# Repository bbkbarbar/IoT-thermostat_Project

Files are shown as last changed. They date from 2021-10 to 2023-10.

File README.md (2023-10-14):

# IoT Thermostat v4.0.2

Custom made thermostat for building's heating control with capability of timing heat-phases when energy price is discounted.
It also has capability of different custom-interfaces (e.g.: show values on smart-mirror, etc.)

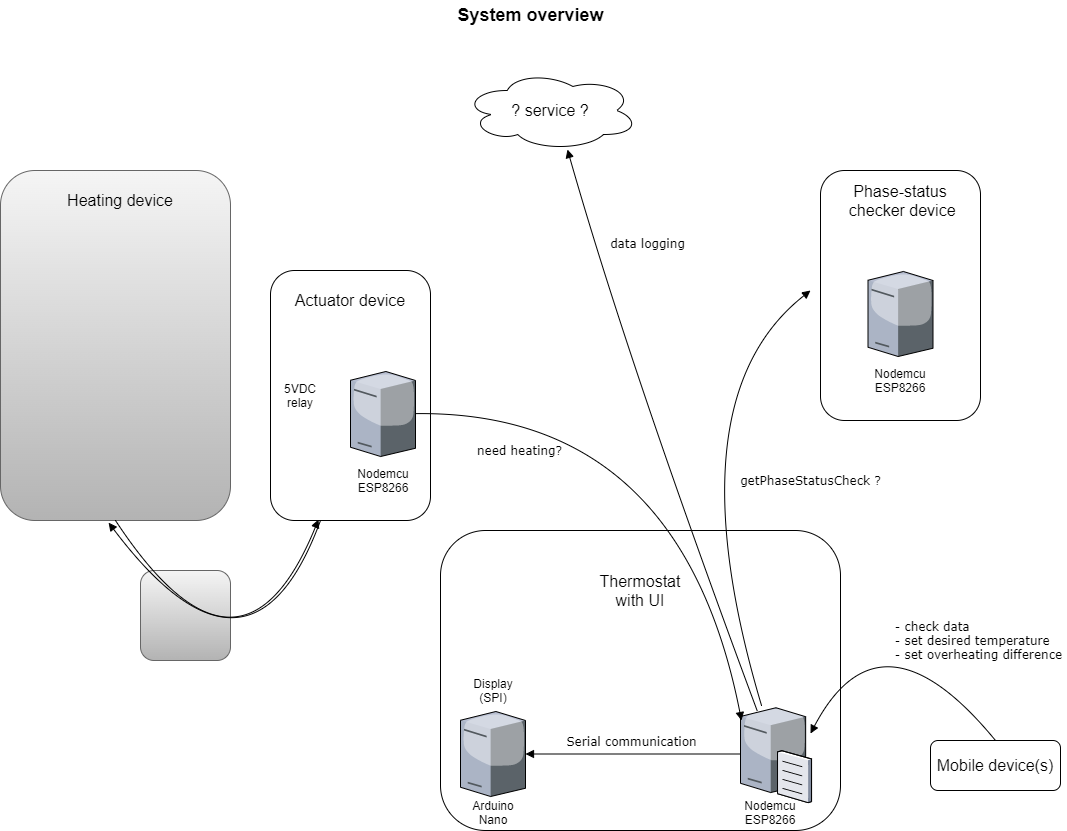
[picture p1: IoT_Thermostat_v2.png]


### Modules:
 - #### [Thermostat](https://github.com/bbkbarbar/IoT-thermostat_Project/tree/main/NodeMcu_IoT_Thermostat_DHT11_with_SerialOut)
   - Measures inside temperature and humidity
   - Can use external temperature resource(s): 
     Any device (HomeAssistant or anything else) can provide temperature value for this thermostat over MQTT
     Due to lack of this "external" data it reverts to using own DTH sensor.
   - get price information from "PhaseChecker"-device
     - .. over MQTT
     - .. by using GET requests to "PhaseChecker"-device
   - Provide command to the "actuator" module (receiver) to control building's heater device
   - Shows informations on OLED display:
     - Current temperature
     - Set temperature
     - Humidity value (rh)
     - Current "price"
     - Current decision (heating or not)

 - #### [Actuator / Receiver](https://github.com/bbkbarbar/IoT-thermostat_Project/tree/main/NodeMcu_IoT_Actuator)
    - Can get action from thermostat module ("Custom mode")
    - Can get action from factory thermostat receiver ("factory mode")
    - Observe control state of factory thermostat receiver

 - #### PhaseChecker device:
    - Provide current status of "low-priced" energy source (currently available or not)

#### Required libraries:
 - ESP8266 Community v2.7.3 (newer not applicable with currently used device(s))

#### Hardware requirement:
- Thermostat
  - NodeMCU board (or WeMos D1 mini also applicable)
  - DHT11 temperature and humidity sensor (DHT22 also applicable)
  - Arduino Nano (other arduino version can also be used)
  - OLED display (0.96" with SPI interface)

- Actuator
  - WeMos D1 mini board (NodeMCU also applicable)
  - Relay module (1ch, low level triggered version)
  - NPN transistor and resistors for control relay-module

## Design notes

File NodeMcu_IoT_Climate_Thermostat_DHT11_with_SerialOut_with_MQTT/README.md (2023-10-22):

# IoT Thermostat v4.0.2



#### Required libraries:
 - ESP8266 Community v2.7.3 (newer not applicable with currently used device(s))

### Version notes:
- 4.0:
   - 4.0.3
     - Filter out any "0°C" current temperature publish (what seems to happens shortly after boot)
   - 4.0.2
     - Thermostat can "receive" cheap-state from external resource over MQTT
   - 4.0.1
     - Thermostat can "receive" temperature values from external sensor(s) via MQTT
- 3.0:
   - 3.0.7
     - Remove AUX heating function from climate device, since it become depricated in HASS_OS 2023.09. 
   - 3.0.6
     - Temperature sensor calibration
     - Humidity sensor calbiration added (-3% currently)
   - 3.0.4
     - Overheat value can be set by mqtt messages 
       By this overheat value can be scheduled by HA.
   - 3.0.3
     - Publish phase state value to easily show in "history" view on dashboards
   - 3.0.2
     - Fix: device will not publish "incredible" data (e.g. humidity < used sensor's min reading value) 
     - Minor changes
   - 3.0.1
     - Modes are used to show the current state:
       - Automatic: Ready, but currently no need for heating
       - Heat: Currently heating
       - OFF: Heating turned off.
   - 3.0.0
     - Act as a Home Assistant compatible "Climate" device

- 2.9:
   - 2.9.1
     - Add MQTT data publish feature as JSON
   - 2.9.0
     - Disable KaaIoT data sendig

- 2.8:
   - 2.8.6
     - Minor changes, add temperature correction according to the last calibration
   - 2.8.5
     - Change order in webUI (Temperature 1st, Set-temperature 2nd)
   - 2.8.4
     - Fix issue when price is unknown and UI shows low price
   - 2.8.3
     - Add "unknown" state for price in KaaIoT updates
   - 2.8.2
     - Add RSSI on webUI
   - 2.8.1
     - Add "margin" (0.1°C) for need-heating? -decision
     - Remove module-name ("UI") from webpage.   
   - 2.8.0
     - Using average of last measured temperature values
- 2.7:
   - Add fuction to check factory control state over actuator device <br>
     and publish this information to KaaIoT
   - Change heeting-feedback from 1/0 to F/_
   - Create common /set endpoint for parameters
- 2.6:
   - Add hostname to WiFi client ✓
   - Send data to KaaIoT ✓ (b32)
   - WebUI 2 (b34) ✓
- 2.5:
   - Query phaseStatus infos from other device over WiFi ✓
   - Handle value settings from REST api calls on specified endpoints ✓
   - Show current data as webpage ✓
   - Serve a specified endpoint for actuator what contains only the needed action ✓

### TODO list:
   - Get static IP for PhaseChecker device and use that in PHASE_CHECKER_IP on this device
   - Add previous state for decision making <br>
     (turn on heanting only if 2 consecutive measuremens justifies that)

   - Use "isnan()" -function (on webUI too)<br>
     Do not show humidity value if temperature is "NAN" (e.g.: after restart)
   - Store elapsed time since last KaaIoT update sent <br>
     for using during average calculations~~ <b>X</b>
   - ~~Use average of last measured temperature values~~ ✓
   - ~~Use "automatic go-back" -function in /set endpoints~~ ✓
   - ~~Create recursive function for getCurrentPhaseState() with retryCount~~ ✓
   - ~~Create new webUI page (based on sample2.html)~~✓
   - ~~Implement color changes in heating's line in webUI 2~~ ✓
   - ~~Data logging on local mock server should works fine~~ ✓
   - tempSet can not be restored properly from EEPROM if it's last value > 255
      (overflow occures)
    Tried to store in 2 places and concatenate.. now working yet.

### Endpoints:
- /result => for checking wanted status by actuator
- /pure => return a JSON object what contains all available data:
   - IoT device id (int)
   - BuildNum (int)
   - location (name like "living room")
   - elapsedTime (long since device started)
   - tempC (float as string)
   - tempF (float as string)
   - humidity (float as string)
   - heatIndex (float as string)
   - targetTemp (float as string)
   - overheatingDiff (float as string)
   - phaseCheckerIP (as string)
   - phaseStatus (1|0)
   - heating (1|0)
- /data => show basic sensor values
- /data2 => show extended sensor values (+ phaseStatus)
- /rst => reboot device insantly
- /set => Set parameters:<br>
  - "/set?temp=235" or "/set?temperature=235" means target temperature = 23,5°C
  - "/set?diff=4" or "/set?overheat=4" means overheating difference = 0,4°C<br>
- Depricated endpoints:
  - /temp => set needed temperature<br>
   "/set?value=235" (means 23,5°C)
  - /overheat => set overheating temperature difference
   "/overheat?value=5" (means 0,5°C)

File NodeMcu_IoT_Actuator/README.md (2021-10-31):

# IoT Actuator



Circuit:
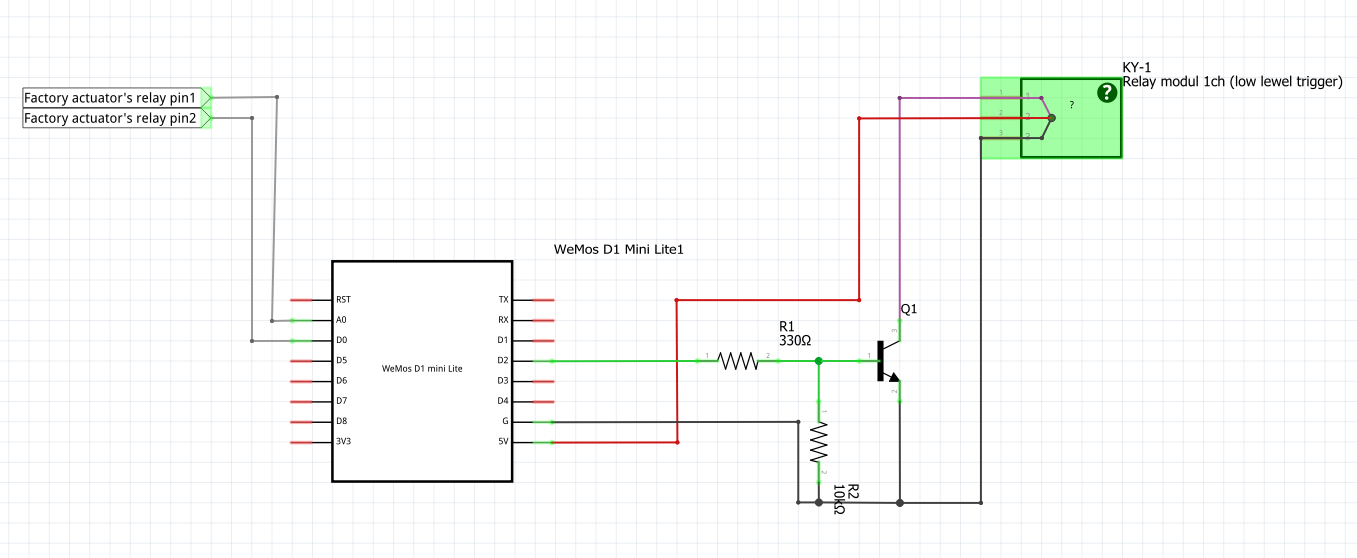
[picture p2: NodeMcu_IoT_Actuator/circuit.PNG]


Required libraries:
 - ESP8266 Community v2.7.3 (newer not applicable with currently used device(s))

 Endpoints:
  - / => Information page
  - /set => set mode (forwarder or actuator)
    - /set?mode=0  means "forwarder mode"
    - /set?mode=1  >> means "actuator mode"
  - /fc => factory thermostat's control state

Versions:
 - v0.1: basic functions
 - v0.2:
   - add "USE_MOCK" macro for using mock server instead of real thermostat
     for testing purpose
   - getting action from thermostat (mock or real) <b>WORKS FINE</b> b4
   - Using human-readable hostname b5
   - WebUI 2 (can shows mock-useage too) b9
 - v0.3:
   - add relay handling
 - v1.0:
     - Can "forward" factory actuator's state
     - Can show factory actuator's state over "/fc" -endpoint
 - v1.2:
     - /set endpoint added. <br>
     Mode can be set over it
 - v1.3:
     - Rename "Actuator" >> "Receiver"
     - WebUI changes (RSSI moved to "table")
     - Minor refactors
     - /set endpoint drop back to main page after few seconds
 - v1.4:
     - Rollback function:
       <br>If "Custom mode" used AND actuator can not get HTTP-200 -response from Thermostat device (for any reason)
       <br>than it automatically goes to "Rollback mode" and uses factory control state
     - v1.4.1:
       <br>In "Rollback mode" WebUI show the thermostat-IP

 TODO list:
  - ~~Add "Rollback" -mode: <br>
    Use "factory" input if thermostat not available for any reaseon~~
  - Consider create set..-endpoint for thermostat IP
  - ~~Figure out WeMos board's pin configuration~~
  - ~~create functions for reading ADC <br>
    for observe heating phases of factory thermostat~~
  - ~~Create circuite for "observe-function"~~
  - ~~create methods for KaaIoT data upload (for observe function)~~ - Solved since Thermostat module reads observed data from Receiver module

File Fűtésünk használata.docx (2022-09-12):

# Fűtés használata:

## Vevő egység (kazán mellett):

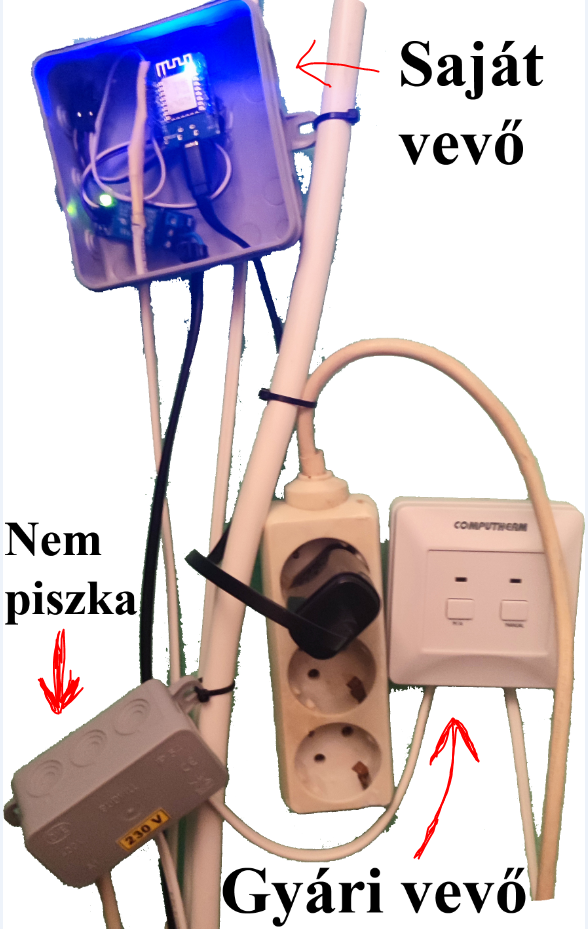
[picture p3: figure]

FONTOS:
A 230V matricás dobozba bejön a 230V-os konnektori „áram”, itt csak „el van osztva” a saját vevőhöz szükséges konnektorhoz és a gyári vevő számára..
FONTOS: az itt levő konnektorba / elosztóba kizárólag olyan dolgot szabad bedugni ami:
1: kevés áramot eszik (telefontöltők ilyesmik, laptop-ig bezárólag OK, PORSZÍVÓ, vasaló, felmosó VÉLETLENÜL SEM!)
2: csak olyasmit aminek a konnektori dugóján nincs földelés ér (a konnektorból kiálló 2 érintkezőt nem használja)
A 230V feliratú dobozt kizárólag csak akkor szabad piszkálni (főleg a barna / fekete vezetéket benne), ha a dolgozó szoba ajtaja mellett / fölött a gardrób oldalán a plafon alatt a fali dobozban ki van kötve az onnan a falon kívül hátra-menő fehér külsejű vezeték!

A saját vevő egy USB-s „telefontöltőről” kap 5V-ot, tehát a saját vevő dobozában nincs semmi ami hálózati feszültséget kapna (nem tud „jobban megrázni” mint egy elem vagy mint a telefontöltőd).

A saját vevő WiFi-n csatlakozik a hálózathoz.
Ha valamiért nem éri el a termosztát egységet WiFi-n akkor visszaáll „Rollback mode”-ba.
Ez annyit jelent, hogy „megnézi”, hogy a gyári vevő egység éppen szeretne-e fűteni vagy sem és ugyanezt az utasítást adja tovább a kazán felé.


FONTOS:
A saját vevő áramtalanítása / kihúzása esetén a gyári termosztát vevője nem tudja bekapcsolni a fűtést!
Csak a gyári állapot visszaállítása után (vezetékek átközése: a fekete külsejű vezeték, ami most a saját vevőhöz megy a kazántól, az ehelyett a gyári termoszát jobb oldali fehér vezetékének a helyére menjen (2 ér sorrendje nem számít)).
Gyári termosztát használata:
Áramtalanítsuk a saját termosztát egységet, ezáltal a „saját vevő” nem találja a termoszátját WiFi-n, így automatikusan visszaáll „Rollback mode”-ba, tehát a gyári tremosztát utasítását továbbítja a kazán számára.
Ebben az esetben állítsd be a kívánt hőmérsékletet a gyári termosztáton (ami amúgy le van véve, hogy ne akarjon fűteni, hagyja, hogy a saját vezérlés működjön)!

Termosztát használata:

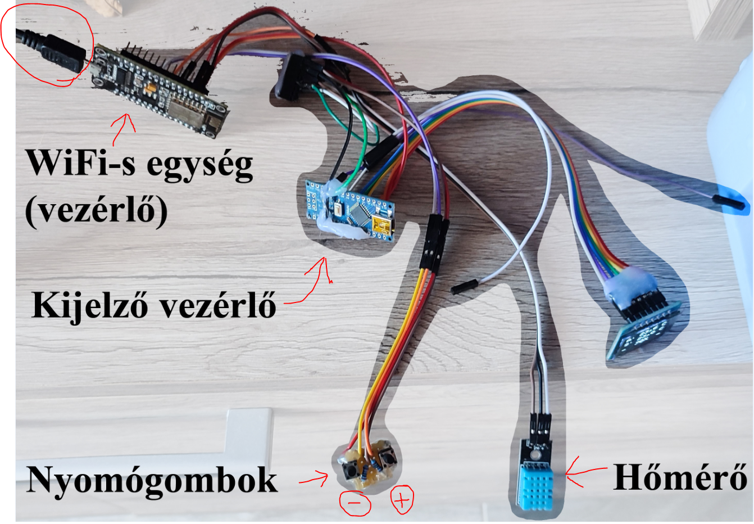
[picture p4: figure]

Kikapcsoláshoz / átamalanításhoz a képen bal felül bekarikázott USB csatlakozót kell kihúzni (vagy az USB kábelt abból, amiről áramot kap).

Termoszát elérhetősége:

Az itthoni WiFi-n bármilyen eszközön (telefon, tablet, számítógép, akár a TV web-böngészőjén)
egy böngészőbe (NEM google keresőbe!, hanem böngészőbe!) írd be:
192.168.1.171

Ekkor ezt látod:

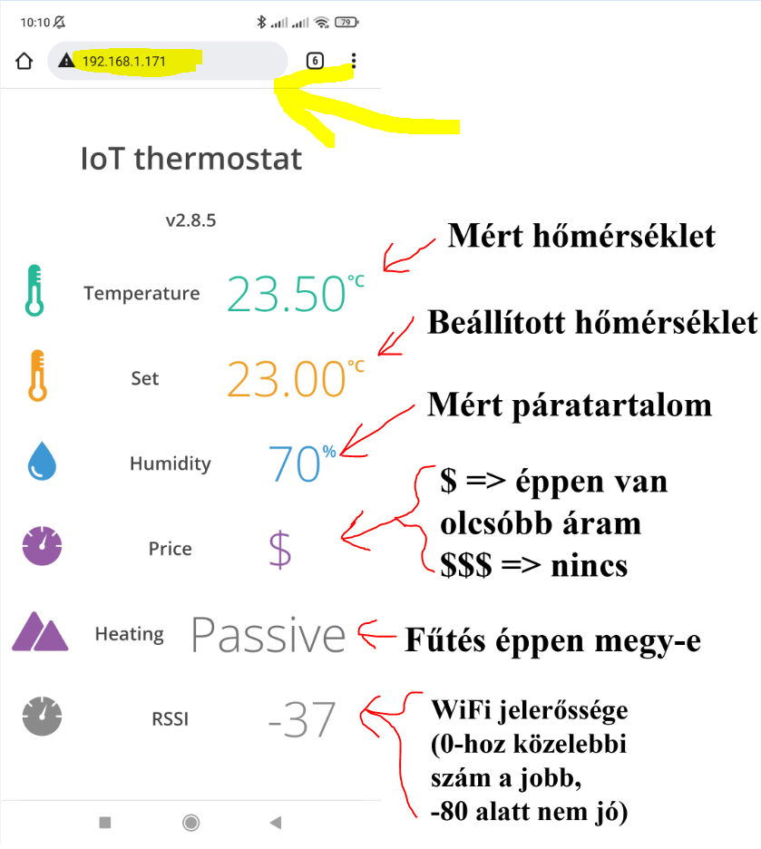
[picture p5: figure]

Hőmérséklet beállítása:

Írd be a böngészőbe ezt (szóközök nélkül!):
192.168.1.171/set?temp=SZÁM
A szám a kívánt hőmérséklet 10x-ese, tehát pl.: 23,6C esetén: 236.
192.168.1.171/set?temp=236
A beállítás után akár 20-30 mp-is eltellhet mire a termosztát saját kijelzőjén megjelenik az új érték
(~ 30mp-enként frissül a kijelző tartalma).
Ugyan ezek a funkciók (a hőmérséklet beállítása is) elérhető neten keresztül bárhonnan, ekkor a termosztát IP-je (192.168.1.171) –rész helyett a „boorfeszek.ddns.net:38837” –címet kell használni (hőmérséklet beállításához ugyanaz a végződés kell) (ez csak akkor megy, ha nem az otthoni WiFi-n van a telefonod, de otthon épp van net).

Termosztát kijelzője:

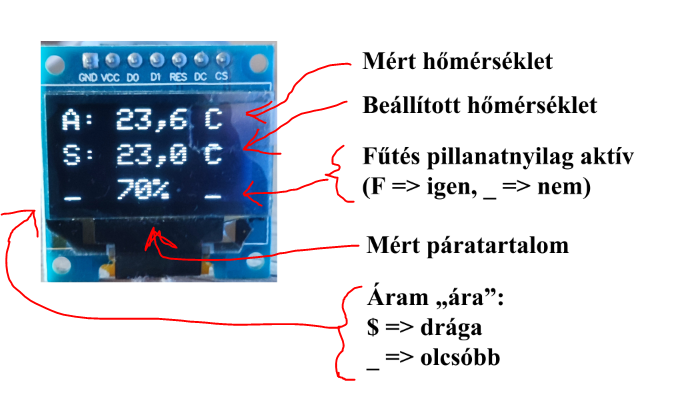
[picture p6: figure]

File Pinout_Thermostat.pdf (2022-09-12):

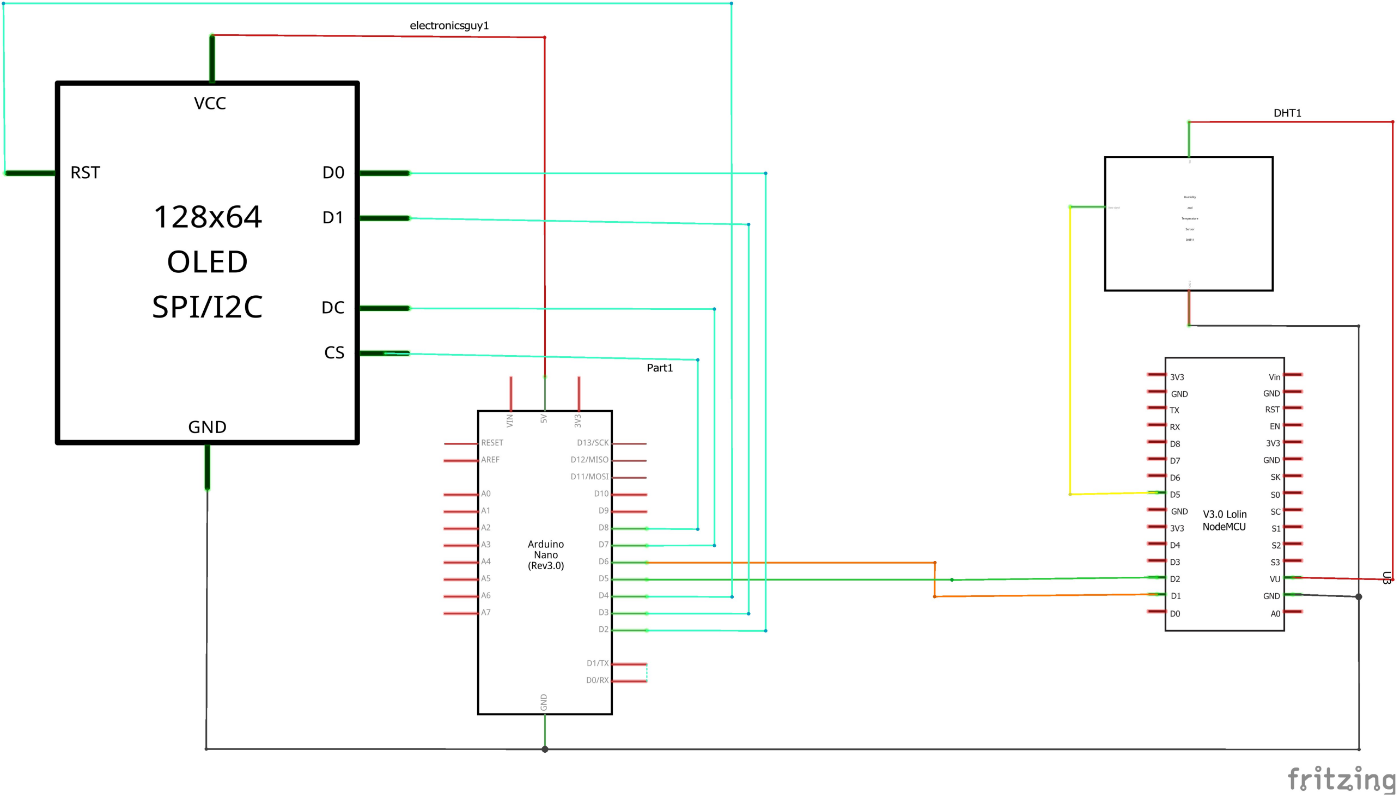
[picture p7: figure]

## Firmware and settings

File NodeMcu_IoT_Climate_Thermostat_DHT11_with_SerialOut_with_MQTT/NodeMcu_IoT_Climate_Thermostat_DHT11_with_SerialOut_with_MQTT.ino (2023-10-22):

#define USE_SECRET  1

//#define USE_2_WAYS_COMMUNICATION
/* It means thermostat tries to get factory control state from receiver (if receiver can provide that) */

/*
 * Used board setting:
 * NodeMCU 1.0 (ESP-12E Module)
 */ 

//#define SHOW_OUTPUTS_FOR_DISLPAY_IN_SERIAL_TOO _


// 1 "TP-Link_BB"    
// 2 "BB_Home2"  
// 3 "P20 Pro"    
// 4 "BB_guest"

//#define USE_TEST_CHANNEL
#define SKIP_KAAIOT_SEND
#define SKIP_TS_COMMUNICATION

#define VERSION                  "v4.0.3"
#define BUILDNUM                      74

#define OWN_SENSOR                     0
#define EXTERNAL_SENSOR                1



/*
 * v3.0.7:
 *   Remove aux heating feature from climate device (since it become depricated in HASSOS 2023.09
 */


/*
 * Add device_name tag for RSSI
 */

#define SERIAL_BOUND_RATE         115200
#define SOFT_SERIAL_BOUND_RATE      9600

// DHT-11 module powered by NodeMCU's 5V 
// DHT-11 connected to D5 of NodeMCU
// Pinout: https://circuits4you.com/2017/12/31/nodemcu-pinout/

//==================================
// MQTT broker
//==================================
#define MQTT_HOST "192.168.1.190"
#define MQTT_PORT 1883

// Temperature MQTT Topic(s)
// _2 refers to IOT_DEVICE_ID
#define MQTT_PUB_TEMP "boorfeszek/iot_thermostat_2/temperature"
#define MQTT_PUB_HUM "boorfeszek/iot_thermostat_2/humidity"
#define MQTT_PUB_HEATING "boorfeszek/iot_thermostat_2/heating"
#define MQTT_PUB_TEMP_SET "boorfeszek/iot_thermostat_2/tempset"
#define MQTT_PUB_OVERHEAT "boorfeszek/iot_thermostat_2/overheat"
#define MQTT_PUB_OVERHEATVAL "boorfeszek/iot_thermostat_2/overheatval"
#define MQTT_PUB_RSSI "boorfeszek/iot_thermostat_2/rssi"
#define MQTT_PUB_DATA "boorfeszek/iot_thermostat_2/json"

#define MQTT_SUB_OHT "boorfeszek/iot_thermostat_2/setoverheat"

// MQTT Subscribe for additional features
#define TOPIC_TEMPERATURE_FROM_HA_SENSOR  "homeassistant/indoor_temp"
#define TOPIC_CHEAP_STATE_SENSOR          "boorfeszek/energy-cheap/state"

#include <SoftwareSerial.h>
#include <DHTesp.h>
#include <ESP8266WiFi.h>
#include <ESP8266WebServer.h>
#include <WiFiClient.h>
#include <ESP8266HTTPClient.h>
#include <EEPROM.h>


#include <Ticker.h>
#include <AsyncMqttClient.h>


// KaaIoT
//#include <PubSubClient.h>
//#include <ArduinoJson.h>
//#include "kaa.h"

#include "secrets.h"
#include "params.h"

#include "mqtt_HA_climate_config.h"

#include "common_methods.h"
#include "webUI2.h"

DHTesp dht;

//==================================
// WIFI
//==================================
const char* ssid =           S_SSID;
const char* password =       S_PASS;

WiFiEventHandler wifiConnectHandler;
WiFiEventHandler wifiDisconnectHandler;
Ticker wifiReconnectTimer;


// =================================
// HTTP
// =================================
ESP8266WebServer server(SERVER_PORT);
HTTPClient http;

AsyncMqttClient mqttClient;
Ticker mqttReconnectTimer;

//==================================
// KaaIoT
//==================================
WiFiClient client;


//==================================
// SoftSerial
//==================================
SoftwareSerial serialOut(SOFT_SERIAL_RX, SOFT_SERIAL_TX);      // (Rx, Tx)

//==================================
// Button handling 
//==================================
//Buttons hooked on D4 and D3 pins
#define BTN_PIN1                  13 // means D7 on NodeMCU board
#define BTN_PIN2                  15 // means D8 on NodeMCU board


//==================================
// EEPROM
//==================================
int eepromAddr =                   1;
int eepromAddr2 =                  4;

int usedSensor = OWN_SENSOR;


//==================================
// "Data" variables
//==================================
float valC = NAN;
float valF = NAN;
float valH = NAN;
float valT = NAN;
float valCExt = NAN;

#define AVG_ARR_SIZE 5
short dataCount = 0;
short nextDataIdx = 0;
float tempDataArr[AVG_ARR_SIZE];


short tempSet = 190; // means 19,0 °C
short overheatingDifference = 0;

short action = NOTHING; // can be NOTHING or HEATING
short currentMode = MODE_HEAT;

int lastTSUpdateStatus = -1;

long updateCount = 0;
String lastPhaseStatus = "";
String receivedPhaseState = "";

//==================================
// Other variables
//==================================
long timeOfLastMeasurement = 0;      //time of the last measurement
long lastWiFiCheck = 0;
int errorCount = 0;

unsigned long elapsedTime = 0;


boolean isValueInRange(float val, float max, float min, String text){

  if( (val != NAN) && (val <= max) && (val >= min) ){
    return true;
  }else{
    Serial.println("\n\n\nINVALID VALUE (" + text + "): " + String(val) + "\n\n");
    return false;
  }
}

boolean isValueSeemsReal(float val, String text){
  return isValueInRange(val, 100.0f, 2.0f, text);
}

float getTemperatureAvgValue(float lastVal){

  // store last value
  tempDataArr[nextDataIdx] = lastVal; 
  
  //move "pointer" of next overrideable array element
  nextDataIdx++;
  if(nextDataIdx >= AVG_ARR_SIZE){
    nextDataIdx = 0;
  }
  

  float res = 0.0;
  
  if(dataCount < AVG_ARR_SIZE){ // we have no enaugh data for calculation2, so we will calculate a basic average of already available values..
    dataCount++;
    for (uint8_t i=0; i<dataCount; i++){
      res += tempDataArr[i];
    }
    return (res / dataCount);
  
  }else{ // we have full array of data

    byte idxMin = 0;
    byte idxMax = 0;
    float minV = tempDataArr[idxMin];
    float maxV = tempDataArr[idxMax];
    for (uint8_t i=1; i<dataCount; i++){
      if(tempDataArr[i] < tempDataArr[idxMin]){
        idxMin = i;
      }
      if(tempDataArr[i] > tempDataArr[idxMax]){
        idxMax = i;
      }
    }

    if(idxMin == idxMax){ // means all element of array is the same value
      // than return with any element of array e.g.: idx0
      return tempDataArr[0];
    }

    // if we reached this line of code than we have an array with different min and max values..
    for (uint8_t i=0; i<AVG_ARR_SIZE; i++){
      // we will get a total value of array elements except the min and max value
      if((i != idxMin) && (i != idxMax)){
        res += tempDataArr[i];  
      }
    }
    return (res / (AVG_ARR_SIZE-2));
    
  }

}


// ==========================================================================================================================
//                                                 Hw feedback function
// ==========================================================================================================================

void turnLED(int state){
  if(state > 0){
    digitalWrite(LED_BUILTIN, LOW);   // Turn the LED on (Note that LOW is the voltage level
    // but actually the LED is on; this is because
    // it is active low on the ESP-01)
  }else{
    digitalWrite(LED_BUILTIN, HIGH);  // Turn the LED off by making the voltage HIGH
  }
}

void ledBlink(int blinkCount, int onTime, int offTime){
  for(short int i=0; i<blinkCount; i++){
    turnLED(ON);
    delay(onTime);                      // Wait for a second
    turnLED(OFF);
    if(i < blinkCount-1){
      delay(offTime);
    }
  }
}

// ==========================================================================================================================
//                                                     Other methods
// ==========================================================================================================================

void doRestart(){
  Serial.println("Restart now...");
  ESP.restart();
}


void saveToEEPROM(int addr, short value){

  byte b1 = value & 0b11111111;
  byte b2 = (value>>8) & 0b11111111;

  Serial.println("Value: " + String(value));
  Serial.println("b1: " + String(b1));
  Serial.println("b2: " + String(b2));
  
  EEPROM.write(addr, b1);
  EEPROM.write(addr+1, b2);
  EEPROM.commit();
}

short loadFromEEPROM(int addr){
  byte b1 = EEPROM.read(addr);
  byte b2 = EEPROM.read(addr+1);

  short value = 0;
  value |= (b2<<8);
  value |= b1;
  return value;
}

// ==========================================================================================================================
//                                                  Web server functions
// ==========================================================================================================================

void HandleNotFound(){
  String message = "File Not Found\n\n";
  message += "URI: ";
  message += server.uri();
  message += "\nMethod: ";
  message += (server.method() == HTTP_GET)?"GET":"POST";
  message += "\nArguments: ";
  message += server.args();
  message += "\n";
  for (uint8_t i=0; i<server.args(); i++){
    message += " " + server.argName(i) + ": " + server.arg(i) + "\n";
  }
  server.send(404, "text/html", message);
}


void actionTempSet(){
  String value = server.arg("value"); //this lets you access a query param (http://x.x.x.x/set?value=12)
  setTargetTemperature(value.toInt());
  float ts = (float)tempSet/10;
  Serial.println("Try to SET: " + String(tempSet) );
  String m = String("Target temperature value set:\n") + String(ts) + "C";
  m+= getHTMLAutomaticGoBack(DELAY_BEFORE_REFRESH_PAGE_AFTER_SET_ENDPOINT_IN_MS);

  //To force quick reaction of set comand
  timeOfLastMeasurement = timeOfLastMeasurement - DELAY_BETWEEN_ITERATIONS_IN_MS;
  server.send(200, "text/html", m );
}

void storeOverHeatValue(){
  // save into eeprom
  saveToEEPROM(eepromAddr2, overheatingDifference);
}

void actionOverheatSet(){
  String value = server.arg("value"); //this lets you access a query param (http://x.x.x.x/set?value=12)
  overheatingDifference = value.toInt();

  storeOverHeatValue();

  float oh = (float)overheatingDifference/10;
  Serial.println("Try to set overheating: " + String(overheatingDifference) );
  String m = String("Overheating value set: ") + String(oh)  + "C";
  m+= getHTMLAutomaticGoBack(DELAY_BEFORE_REFRESH_PAGE_AFTER_SET_ENDPOINT_IN_MS);

  //To force quick reaction of set comand
  timeOfLastMeasurement = timeOfLastMeasurement - DELAY_BETWEEN_ITERATIONS_IN_MS;
  server.send(200, "text/html", m );

  publishData(); // publish data as a standalone mqtt device..
}

void setTargetTemperature(int valueInt){
  // save into eeprom
  tempSet = valueInt;
  saveToEEPROM(eepromAddr, tempSet);

  Serial.println("Try to SET: " + String(tempSet) );
  //TODO: update display content

  //TODO: if MQTT is connected -> publish tempSet Value
  //if(mqttClient.isConnected())
    float tsF = (tempSet/10.0f);
    publishTempSet(tsF);
    //Serial.println("Publish done: |" + String(pl) + "|");

    if( (usedSensor == EXTERNAL_SENSOR) && (valCExt != NAN)){
      publishCurrentTemp(valCExt);
    }else{
      publishCurrentTemp(valC);
    }

    publishData(); // publish data as a standalone mqtt device..

    decide(); //MAYBE not needed
  
}

void actionSet(){
  String m = "";
  for (uint8_t i=0; i<server.args(); i++){
    if( (server.argName(i) == String(ARG_TEMP_SET1)) || (server.argName(i) == String(ARG_TEMP_SET2)) ){
        // TEMP_SET
        String value = server.arg(i);
        setTargetTemperature(value.toInt());

        float ts = (float)tempSet/10;
        m += String("<br>Target temperature value set:\n") + String(ts) + "C\n<br>";

        //To force quick reaction of set comand
        timeOfLastMeasurement = timeOfLastMeasurement - DELAY_BETWEEN_ITERATIONS_IN_MS;
    }
    if( (server.argName(i) == String(ARG_OVERHEAT1)) || (server.argName(i) == String(ARG_OVERHEAT2)) ){
        // OVERHEAT
        String value = server.arg(i);
        overheatingDifference = value.toInt();

        // save into eeprom
        saveToEEPROM(eepromAddr2, overheatingDifference);

        Serial.println("Try to set overheating: " + String(overheatingDifference) );
        float oh = (float)overheatingDifference/10;
        m += String("Overheating value set: ") + String(oh)  + "C\n<br>";

        publishData(); // publish data as a standalone mqtt device..

        //To force quick reaction of set comand
        timeOfLastMeasurement = timeOfLastMeasurement - DELAY_BETWEEN_ITERATIONS_IN_MS;
    }
  }
  
  m+= getHTMLAutomaticGoBack(DELAY_BEFORE_REFRESH_PAGE_AFTER_SET_ENDPOINT_IN_MS);
  server.send(200, "text/html", m );
}



void HandleNotRstEndpoint(){
  doRestart();
}



void HandleRoot(){
  //Serial.println("HandleRoot called...");
  //String message = "<!DOCTYPE html><html lang=\"en\">";
  //message += "<head><meta charset=\"utf-8\"><meta name=\"viewport\" content=\"width=device-width, initial-scale=1\"></head>";
  String message = "";
  short price = 0;
  if(lastPhaseStatus == String(PHASE_STATUS_CHEAP)){
    price = 0;
  }else{
    price = 1;
  }
  message = sendHTML(valC, ((float)(tempSet)/10), valH, price, action, WiFi.RSSI(), usedSensor, valCExt);
  /*
  message = generateHtmlHeader();
  message += generateHtmlBody();
  /**/
  server.send(200, "text/html", message );
}


String getCurrentPhaseState(int retryCount){

    if((receivedPhaseState != "") && (receivedPhaseState != PHASE_STATUS_UNKNOWN)){
      return receivedPhaseState;
    }
    else{

      WiFiClient myWC;
      // old
      //http.begin("192.168.1.170:81/data");  //Specify request destination
      // new
      String statusServerPath = "http://" + String(PHASE_CHECKER_IP) + ":81/data";
      http.begin(myWC, statusServerPath.c_str());  //Specify request destination


      int httpCode = http.GET();                                  //Send the request
      //Serial.print("PhaseStatus - resultCode: " + String(httpCode) + " ps: ");
      
      String payload = "";
      if (httpCode > 0) { //Check the returning code
        payload = http.getString();   //Get the request response payload
        //Serial.print(payload);
        //Serial.println(payload);             //Print the response payload
      }else{
        payload = String(PHASE_STATUS_UNKNOWN);
        Serial.println("httpCode: " + String(httpCode));
      }
      http.end();   //Close connection

      if( (retryCount > 0) && (payload == String(PHASE_STATUS_UNKNOWN)) ){
        // probably need to retry
        return getCurrentPhaseState(--retryCount);
      }else{
        return payload;
      }
    }
}



String getFactoryControlState(int retryCount){
    #ifdef USE_2_WAYS_COMMUNICATION
      WiFiClient myWC;
      // old
      //http.begin("192.168.1.170:81/data");  //Specify request destination
      // new
      String statusServerPath = String(ACTUATOR_URL) + "/fc";
      http.begin(myWC, statusServerPath.c_str());  //Specify request destination


      int httpCode = http.GET();                                  //Send the request
      //Serial.print("PhaseStatus - resultCode: " + String(httpCode) + " ps: ");
      
      String payload = "";
      if (httpCode > 0) { //Check the returning code
        payload = http.getString();   //Get the request response payload
        //Serial.print(payload);
        //Serial.println(payload);             //Print the response payload
      }else{
        payload = String(FC_STATUS_UNKNOWN);
        Serial.println("httpCode: " + String(httpCode));
      }
      http.end();   //Close connection

      Serial.println("FactoryState: " + payload);

      if( (retryCount > 0) && (payload == String(FC_STATUS_UNKNOWN)) ){
        // probably need to retry
        return getFactoryControlState(--retryCount);
      }else{
        return payload;
      }
    #else
      return FC_STATUS_UNKNOWN;
    #endif
}


#ifdef DEBUG_MODE
void sendLogs(String lastPhaseStatus, String temperature , String ts , String oh , String heating){
     //Declare an object of class HTTPClient

    String getData = "?ps=" + lastPhaseStatus + "&temp=" + temperature + "&tempSet=" + ts + "&overheat=" + oh + "&heating=" + heating;
    
    // new
    String logServerPath = "http://192.168.1.141:8083/datalogger2" + getData;
    http.begin(client, logServerPath.c_str());  //Specify request destination

    http.addHeader("Content-Type", "text/plain");
    int httpCode = http.GET();                                  //Send the request

    Serial.println("Logs sent: " + getData);

    //Close connection
    http.end();   //Close connection
}
#endif


// #include "kaaIotFunctions.h"

void GetNeededAction(){
  String message = "" + String(action);
  server.send(200, "text/html", message );
}

void HandleData(){
  //Serial.println("HandleData called...");
  String message = "" +  String(valC) + " " +  String(valH);
  server.send(200, "text/html", message );
}

void HandleMultipleData(){
  //Serial.println("HandleData called...");
  String message = "" +  String(valC) + "|" +  String(valH) + "|" + lastPhaseStatus;
  server.send(200, "text/html", message );
}


void showPureValues(){
  Serial.println("showPureValues() called...");
  float ts = ((float)tempSet) / 10;
  float ohd = ((float)overheatingDifference) / 10;
  String message = "{\n";
  
  message += "\t\"IoT device id\": \"" + String(IOT_DEVICE_ID) + "\",\n";
  message += "\t\"BuildNum\": \"" + String(BUILDNUM) + "\",\n";
  message += "\t\"location\": \"" + String(LOCATION_NAME) + "\",\n";
  message += "\t\"elapsedTime\": \"" + String(elapsedTime) + "\",\n";
  message += "\t\"values\": {\n";
  message += "\t\t\"tempC\": \"" + String(valC) + "\",\n";
  message += "\t\t\"tempF\": \"" + String(valF) + "\",\n";
  message += "\t\t\"humidity\": \"" + String(valH) + "\",\n";
  message += "\t\t\"heatIndex\": \"" + String(valT) + "\"\n";
  message += "\t},\n";
  message += "\t\"parameters\": {\n";
  message += "\t\t\"targetTemp\": \"" + String(ts) + "\",\n";
  message += "\t\t\"overheatingDiff\": \"" + String(ohd) + "\"\n";
  message += "\t},\n";
  message += "\t\"phaseChecker\": {\n";
  message += "\t\t\"phaseCheckerIP\": \"" + String(PHASE_CHECKER_IP) + "\",\n";
  message += "\t\t\"phaseStatus\": \"" + lastPhaseStatus + "\"\n";
  message += "\t},\n";
  message += "\t\"heating\": \"" + String(action) + "\"\n";
  message += "}\n";
  server.send(200, "text/json", message );
}



// ==========================================================================================================================
//                                                        WiFi handling
// ==========================================================================================================================

//orig:
void connectToWifi(){
  // Setup WIFI
  WiFi.begin(S_SSID, S_PASS);
  
  Serial.println("MQTT server set to: " + String(MQTT_HOST));
  Serial.println("Try to connect (SSID: " + String(ssid) + ")");
  
  // Wait for WIFI connection
  int tryCount = 0;
  while ( (WiFi.status() != WL_CONNECTED) && (tryCount < WIFI_TRY_COUNT)) {
    delay(WIFI_WAIT_IN_MS);
    tryCount++;
    Serial.print(".");
  }
}

void initWiFi(){

  connectToWifi();
  if(WiFi.status() == WL_CONNECTED){
    Serial.println("");
    Serial.println("Connected");
    String ipMessage = "I" + WiFi.localIP().toString();
    serialOut.println(ipMessage);
    //Serial.println("SENT: " + ipMessage );
    
    // for reconnecting feature
    WiFi.setAutoReconnect(true);
    WiFi.persistent(true);
    WiFi.hostname(String(SOFTWARE_NAME) + " " + String(MODULE_NAME) + " " + String(VERSION) + " b" + String(BUILDNUM));
  }else{
    Serial.println("");
    Serial.print("ERROR: Unable to connect to ");
    Serial.println(ssid);
    doRestart();
  }
}

void onWifiConnect(const WiFiEventStationModeGotIP& event) {
  Serial.println("Connected to Wi-Fi.");
  connectToMqtt();
}

void onWifiDisconnect(const WiFiEventStationModeDisconnected& event) {
  Serial.println("Disconnected from Wi-Fi.");
  mqttReconnectTimer.detach(); // ensure we don't reconnect to MQTT while reconnecting to Wi-Fi
  wifiReconnectTimer.once(2, connectToWifi);
}

void connectToMqtt() {
  Serial.println("Connecting to MQTT...");
  mqttClient.connect();
}

void publishCurrentTemp(float tempVal){

  if(isValueSeemsReal(tempVal, "temperature to publish") == false){
    return;
  }

  //Serial.println("\n\n\nStart publishing temperatureValue: " + String(tempVal) + "\n\n");
  String str = String(tempVal);
  int len = str.length();
  char* payload ="    ";
  str.toCharArray(payload, len);

  uint16_t packetIdPub1 = mqttClient.publish(TOPIC_FEEDBACK_CURR_TEMP, 1, true, payload);
  Serial.print("Publishing at QoS 1, packetId: ");
  Serial.println(packetIdPub1);

}

void publishMode(){
  if(currentMode == MODE_HEAT){
    uint16_t packetIdPub1 = mqttClient.publish(TOPIC_FEEDBACK_FOR_HA_MODE, 1, true, "heat");
    Serial.print("Publishing at QoS 1, packetId: ");
    Serial.println(packetIdPub1);
  } else
  if(currentMode == MODE_AUTO){
    uint16_t packetIdPub1 = mqttClient.publish(TOPIC_FEEDBACK_FOR_HA_MODE, 1, true, "auto");
    Serial.print("Publishing at QoS 1, packetId: ");
    Serial.println(packetIdPub1);
  } else
  if(currentMode == MODE_OFF){
    uint16_t packetIdPub1 = mqttClient.publish(TOPIC_FEEDBACK_FOR_HA_MODE, 1, true, "off");
    Serial.print("Publishing at QoS 1, packetId: ");
    Serial.println(packetIdPub1);
  }

}

void publishTempSet(float setVal){
  if(isValueSeemsReal(setVal, "tempSET to publish") == false){
    return;
  }
  String str = String(setVal);
  int len = str.length();
  char* payload ="    ";
  str.toCharArray(payload, len);

  uint16_t packetIdPub1 = mqttClient.publish(TOPIC_FEEDBACK_FOR_HA_TEMP_SET, 1, true, payload);
  Serial.print("Publishing at QoS 1, packetId: ");
  Serial.println(packetIdPub1);
}
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
void loop() {
  long now = millis();
  server.handleClient();
  wifiConnectionCheck(now);
  sensorLoop(now);
}

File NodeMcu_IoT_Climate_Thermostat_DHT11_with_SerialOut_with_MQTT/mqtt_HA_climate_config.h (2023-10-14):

//OLD: char* configStr = "{\"curr_temp_t\": \"homeassistant/climate/5002914e77b2/iot_thermostat/ctt\", \"aux_cmd_t\": \"homeassistant/climate/5002914e77b2/iot_thermostat/act\"," "\"aux_stat_t\": \"homeassistant/climate/5002914e77b2/iot_thermostat/ast\"," "\"away_mode_cmd_t\": \"homeassistant/climate/5002914e77b2/iot_thermostat/amct\",  \"away_mode_stat_t\": \"homeassistant/climate/5002914e77b2/iot_thermostat/amst\", \"hold_cmd_t\": \"homeassistant/climate/5002914e77b2/iot_thermostat/hct\", \"hold_stat_t\": \"homeassistant/climate/5002914e77b2/iot_thermostat/hst\", \"min_temp\": 19, \"max_temp\": 27, \"temp_step\": 0.1, \"temp_cmd_t\": \"homeassistant/climate/5002914e77b2/iot_thermostat/ttct\", \"temp_stat_t\": \"homeassistant/climate/5002914e77b2/iot_thermostat/ttst\", \"mode_cmd_t\": \"homeassistant/climate/5002914e77b2/iot_thermostat/mct\", \"mode_stat_t\": \"homeassistant/climate/5002914e77b2/iot_thermostat/mst\", \"modes\": [   \"off\", \"auto\", \"heat\" ], \"name\": \"IoT Termosztát\", \"uniq_id\": \"iot_thermostat_5002914e77b2\", \"dev\": {   \"ids\": \"5002914e77b2\",   \"name\": \"IoT_Thermostat\",   \"sw\": \"1.0.0\" }, \"ret\": true }";
char* configStr = "{\"curr_temp_t\": \"homeassistant/climate/5002914e77b2/iot_thermostat/ctt\", \"away_mode_cmd_t\": \"homeassistant/climate/5002914e77b2/iot_thermostat/amct\",  \"away_mode_stat_t\": \"homeassistant/climate/5002914e77b2/iot_thermostat/amst\", \"hold_cmd_t\": \"homeassistant/climate/5002914e77b2/iot_thermostat/hct\", \"hold_stat_t\": \"homeassistant/climate/5002914e77b2/iot_thermostat/hst\", \"min_temp\": 19, \"max_temp\": 27, \"temp_step\": 0.1, \"temp_cmd_t\": \"homeassistant/climate/5002914e77b2/iot_thermostat/ttct\", \"temp_stat_t\": \"homeassistant/climate/5002914e77b2/iot_thermostat/ttst\", \"mode_cmd_t\": \"homeassistant/climate/5002914e77b2/iot_thermostat/mct\", \"mode_stat_t\": \"homeassistant/climate/5002914e77b2/iot_thermostat/mst\", \"modes\": [   \"off\", \"auto\", \"heat\" ], \"name\": \"IoT Termosztát\", \"uniq_id\": \"iot_thermostat_5002914e77b2\", \"dev\": {   \"ids\": \"5002914e77b2\",   \"name\": \"IoT_Thermostat\",   \"sw\": \"1.0.0\" }, \"ret\": true }";

// Publish
#define TOPIC_MQTT_CLIMATE_CONFIG         "homeassistant/climate/5002914e77b2/iot_thermostat/config"
#define TOPIC_FEEDBACK_FOR_HA_TEMP_SET    "homeassistant/climate/5002914e77b2/iot_thermostat/ttst"
#define TOPIC_FEEDBACK_FOR_HA_MODE        "homeassistant/climate/5002914e77b2/iot_thermostat/mst"
#define TOPIC_FEEDBACK_CURR_TEMP          "homeassistant/climate/5002914e77b2/iot_thermostat/ctt"

// Subscribe
#define TOPIC_CMD_FROM_HA_TEMP_SET        "homeassistant/climate/5002914e77b2/iot_thermostat/ttct"
#define TOPIC_CMD_FROM_HA_MODE            "homeassistant/climate/5002914e77b2/iot_thermostat/mct"

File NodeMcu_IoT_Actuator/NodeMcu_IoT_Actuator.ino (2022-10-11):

// Used board setting:
// WeMos D1 R1


#define USE_SECRET  1
//#define USE_MOCK

// 1 "TP-Link_BB"    
// 2 "BB_Home2"  
// 3 "P20 Pro"    
// 4 "BB_guest"

//#define USE_TEST_CHANNEL
#define SKIP_TS_COMMUNICATION

#define VERSION                 "v1.4.2"
#define BUILDNUM                      23

#define SERIAL_BOUND_RATE         115200
#define SOFT_SERIAL_BOUND_RATE      9600

// Pinout: https://circuits4you.com/2017/12/31/nodemcu-pinout/

#include <SoftwareSerial.h>
#include <ESP8266WiFi.h>
#include <ESP8266WebServer.h>
#include <WiFiClient.h>
#include <ESP8266HTTPClient.h>
#include <EEPROM.h>

#include "secrets.h"
#include "params.h"

#include "actuator_ui2.h"
#include "common_methods.h"


//==================================
// WIFI
//==================================
const char* ssid =           S_SSID;
const char* password =       S_PASS;



// =================================
// HTTP
// =================================
ESP8266WebServer server(SERVER_PORT);
HTTPClient http;


//==================================
// ThingSpeak
//==================================
WiFiClient client;

//==================================
// EEPROM
//==================================
#define EEPROM_ADDR_MODE           8
#define EEPROM_ADDR_IP1            1
#define EEPROM_ADDR_IP2            2
#define EEPROM_ADDR_IP3            3
#define EEPROM_ADDR_IP4            4


//==================================
// "Data" variables
//==================================

short action = NOTHING; // can be NOTHING or HEATING

short modeSet = MODE_FORWARDER;
short modeToShow = modeSet;

//==================================
// Other variables
//==================================
long lastWiFiCheck = 0;
long lastCheck = 0;
int errorCount = 0;

unsigned long elapsedTime = 0;


// ==========================================================================================================================
//                                                     Hw function
// ==========================================================================================================================

String readFactoryInput(){
  //TODO
  int adc = analogRead(A0);
  if(adc > 680){
    Serial.println("Factory input: " + String(NEEDED_ACTION_HEATING) );
    return String(NEEDED_ACTION_HEATING);
  }
  if(adc < 340){
    Serial.println("Factory input: " + String(NEEDED_ACTION_NOTHING) );
    return String(NEEDED_ACTION_NOTHING);
  }
  Serial.println("Factory input: " + String(NEEDED_ACTION_UNKNOWN) );
  return String(NEEDED_ACTION_UNKNOWN);
}


// ==========================================================================================================================
//                                                     Other methods
// ==========================================================================================================================

void doRestart(){
  Serial.println("Restart now...");
  ESP.restart();
}



// ==========================================================================================================================
//                                                  Web server functions
// ==========================================================================================================================


void HandleNotFound(){
  String message = "File Not Found\n\n";
  message += "URI: ";
  message += server.uri();
  message += "\nMethod: ";
  message += (server.method() == HTTP_GET)?"GET":"POST";
  message += "\nArguments: ";
  message += server.args();
  message += "\n";
  for (uint8_t i=0; i<server.args(); i++){
    message += " " + server.argName(i) + ": " + server.arg(i) + "\n";
  }
  server.send(404, "text/html", message);
}


void HandleNotRstEndpoint(){
  doRestart();
}

void HandleRoot(){
  String message = "";
  message = getHTML(action, WiFi.RSSI(), modeToShow);
  /*
  message = generateHtmlHeader();
  message += generateHtmlBody();
  /**/
  server.send(200, "text/html", message );
}

void HandleGetFactoryControlState(){
  server.send(200, "text/html", readFactoryInput() );
  Serial.println("Factory control value sent..");
}

void actionModeSet(){
  String value = server.arg("mode"); //this lets you access a query param (http://x.x.x.x/set?value=12)
  short wantedMode = value.toInt();

  if( (wantedMode == 1) || (wantedMode == 7)){
    modeSet = MODE_ACTUATOR;
  }else{
    modeSet = MODE_FORWARDER;
  }
  
  // save into eeprom
  EEPROM.write(EEPROM_ADDR_MODE, modeSet);
  EEPROM.commit();

  
  String m = "Mode set to: " + (modeSet==MODE_FORWARDER?String("FORWARDER"):String("Actuator"));
  m += getHTMLAutomaticGoBack(3000);
  
  server.send(200, "text/html", m );/**/
}

String getNeededAction(){
    // old
    //http.begin("192.168.1.170:81/data");  //Specify request destination

    WiFiClient wc;
    
    String thermostatServerPath = "http://" + String(THERMOSTAT_IP) + "/result";
    http.begin(wc, thermostatServerPath.c_str());  //Specify request destination

    int httpCode = http.GET();                                  //Send the request
    
    String payload = "";
    Serial.println("httpCode: " + String(httpCode));
    if (httpCode == 200) { //Check the returning code
      payload = http.getString();   //Get the request response payload
    }else{
      payload = String(NEEDED_ACTION_UNKNOWN);
      //Serial.println("httpCode: " + String(httpCode));
    }
    //Serial.println("");
 
    http.end();   //Close connection
    Serial.println("Wanted action: " + payload);

    return payload;
}

void HandleData(){
  //Serial.println("HandleData called...");
  String message = "TODO here";
  server.send(200, "text/html", message );
}



// ==========================================================================================================================
//                                                        WiFi handling
// ==========================================================================================================================

int connectToWiFi(String ssid, String pw){
  // Setup WIFI
  WiFi.begin(ssid, password);
  Serial.println("Try to connect (SSID: " + String(ssid) + ")");
  
  // Wait for WIFI connection
  int tryCount = 0;
  while ( (WiFi.status() != WL_CONNECTED) && (tryCount < WIFI_TRY_COUNT)) {
    delay(WIFI_WAIT_IN_MS);
    tryCount++;
    Serial.print(".");
  }

  if(WiFi.status() == WL_CONNECTED){
    return 1;
  }else{
    return 0;
  }
}


int initWiFi(){
  
  if(connectToWiFi(ssid, password)){
    Serial.println("");
    Serial.println("Connected");
    
    // for reconnecting feature
    WiFi.setAutoReconnect(true);
    WiFi.persistent(true);
    WiFi.hostname("IoT th " + String(MODULE_NAME) + " " + String(VERSION) + " b" + String(BUILDNUM));
  }else{
    Serial.println("");
    Serial.print("ERROR: Unable to connect to ");
    Serial.println(ssid);
    doRestart();
  }
}
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

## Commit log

2021-10-24 Add missing data for json endpoint - b24
    Add:
    - phaseChecker's IP
    - targetTemp
    - overHeatingDiff
    - heating action's current state
    + minor refactors
    [NodeMcu_IoT_Thermostat_DHT11_with_SerialOut.ino]
2021-10-24 BuildNum shown on Json endpoint - b25
    and minor refactors.
    + BUG noticed: can not store tempSet value if it's > 255 (value stored in EEPROM as short???)
    [NodeMcu_IoT_Thermostat_DHT11_with_SerialOut.ino]
2021-10-24 M.C. + TODO list added with known bug(s) - b26
    [NodeMcu_IoT_Thermostat_DHT11_with_SerialOut.ino]
2021-10-25 initial (non-tested) version of IoT Actuator part
2021-10-25 Data logging should works
    Does not work with running MockService on PC
    [NodeMcu_IoT_Thermostat_DHT11_with_SerialOut.ino]
2021-10-25 Looks good BUT did not work with relay - b2
    [NodeMcu_IoT_Actuator.ino, params.h]
2021-10-30 Add KaaIoT update funcion (buggy) b11
    [NodeMcu_IoT_Actuator.ino, params.h]
2021-10-30 Add circuit
    [Actuator_unit.fzz]
2021-10-30 v1.0 Can forward factory actuator's state b14
    [Actuator_unit.fzz]
2021-10-30 Mode loading fixed (b18)
    Mode loading from EEPROM fixed
    [NodeMcu_IoT_Actuator.ino]
2021-10-31 UI sample changed to correspond the current ver.
2021-11-01 Common /set endpoint - b38
    Create common /set endpoint for tempSet and overheat parameters.
    [NodeMcu_IoT_Thermostat_DHT11_with_SerialOut.ino, params.h]
2021-11-01 v2.8 Using average value of temperature (b39)
    It uses the average of last 5 measurements (except the min and the max valueof of those)
    to avoid using faulty measurements (spikes)
2021-11-03 v2.8.4 fix price feedback issue - b43
    [NodeMcu_IoT_Thermostat_DHT11_with_SerialOut.ino, params.h]
2021-12-10 Temp correction set according to "+1C" place
    [Thermostat_unit.fzz]
2022-01-12 Temperature correction set by calibration
    [NodeMcu_IoT_Thermostat_DHT11_with_SerialOut.ino, params.h]
2022-09-06 Thermostat will be HA compatible "Climate" device
    [Thermostat_unit.fzz]
2022-09-09 Device will NOT publish unreal values
    It published invalid initial values (float.MAX, etc) after initialization.
2022-09-12 Add extra files
    [Circuits.fzz]
2022-09-12 Overheat can be set via MQTT
    [NodeMcu_IoT_Climate_Thermostat_DHT11_with_SerialOut_with_MQTT.ino]
2022-09-13 calibrate temperature sensor correction
    [NodeMcu_IoT_Climate_Thermostat_DHT11_with_SerialOut_with_MQTT.ino, params.h]
2022-09-16 Calibration value seems OK
2022-10-07 v3.0.6 b68
    Temperature calibration modified
    Humidity calibration added
2023-09-27 v3.0.7 b69
    Remove depricated AUX_heating feature from MQTT climate device (it's mqtt config)
2023-10-14 Thermostat can use external temperature sensor
2023-10-14 v4.0.2 Thermostat can use ext. temp. sensor
2023-10-22 Filter out any "0°C" current temperature publish
